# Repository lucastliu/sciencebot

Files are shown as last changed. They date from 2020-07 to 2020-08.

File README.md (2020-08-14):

<!-- PROJECT SHIELDS -->
<!--
*** https://www.markdownguide.org/basic-syntax/#reference-style-links
-->

[][license-url]

<!-- PROJECT LOGO -->
<br />
<p align="center">
  <a href="https://github.com/lucastliu/sciencebot">
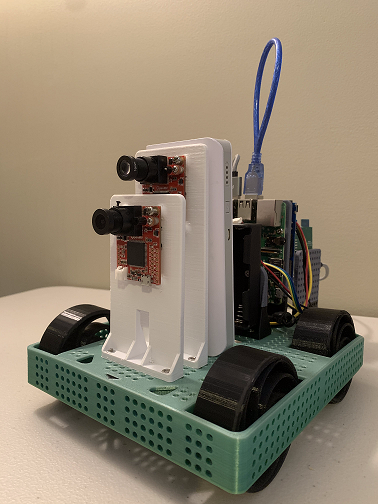
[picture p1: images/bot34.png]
sciencebot
    
  </a>

  <h3 align="center">sciencebot</h3>

  <p align="center">
    A modular & economical research vehicle platform
    <br />
    <a href="https://github.com/lucastliu/sciencebot/wiki">Wiki</a>
    ·
    <a href="https://github.com/lucastliu/sciencebot/blob/master/HARDWARE.md">Hardware</a>
    ·
    <a href="https://github.com/lucastliu/sciencebot/issues">Request Feature</a>
    <br />
    <a href="https://github.com/lucastliu/sciencebot/wiki/System-Capabilities"><b>See sciencebot in action » </b></a>
  </p>
</p>

# Software

Software documentation for setting up the sciencebot, ROS2, and turtlesim.
<!-- TABLE OF CONTENTS -->
## Table of Contents

- [Technologies](#technologies)
- [Project Structure](#project-structure)
- [Getting Started](#getting-started)
  * [Prerequisites](#prerequisites)
    + [Raspberry Pi](#raspberry-pi)
    + [BNO055 IMU](#bno055-imu)
    + [DWM1001](#dwm1001)
    + [OpenMV Cam H7 (Optional)](#openmv-cam-h7--optional-)
    + [Arduino](#arduino)
    + [ROS2 Eloquent Elusor](#ros2-eloquent-elusor)
  * [Installation](#installation)
- [Usage](#usage)
  * [Spin up](#spin-up)
  * [turtlesim basic](#turtlesim-basic)
  * [turtlesim PID control](#turtlesim-pid-control)
  * [sciencebot](#sciencebot)
    + [Manual Drive](#manual-drive)
    + [Automatic XY Waypoint Seeking](#automatic-xy-waypoint-seeking)
    + [Heading Seeking](#heading-seeking)
  * [PlotJuggler](#plotjuggler)
- [Tuning & Modifying](#tuning---modifying)
  * [Tune & MoveTo](#tune---moveto)
  * [ROS Nodes](#ros-nodes)
- [Helpful Tips](#helpful-tips)
- [Resources](#resources)
- [Future](#future)
- [Contributing](#contributing)
- [License](#license)
- [Contact](#contact)

## Technologies

* Raspbian Buster OS
* Arduino
* Python
* C++
* ROS2 Eloquent Elusor

## Project Structure
The `dev_ws` folder contains a full ROS2 based implementation of the vehicle control project.

within `dev_ws`, source code is organized into packages under the `src` folder

Other folders contain basic standalone scripts for individual components (not tied to ROS2 in any way).

See seperate [Hardware Documentation](https://github.com/lucastliu/sciencebot/blob/master/HARDWARE.md) for details on the physical vehicle build, and sensor information

<!-- GETTING STARTED -->
## Getting Started

### Prerequisites

#### Raspberry Pi

  This project was developed on a Raspberry Pi 3B+ running Raspian Buster. Setups that use other Pi hardware or OS versions, or even other Linux devices, will likely operate in a highly similar fashion, but not in the exact same manner.

0. Python 3

    This project requires Python 3. This should be available by default on the Pi with Raspbian Buster.

1. Storage

    Running with Raspbian Buster, the minimum SD card size is 8 GB. However, running this project will require more resources, and a 16 GB card was found to be inadequate as well. A `64 GB micro SD` was used in the build, and is easily sufficient.

2. Virtual Memory

    Due to the limited abilites of an RPi, during installation, it is often useful / necessary to leverage [swap space](https://access.redhat.com/documentation/en-us/red_hat_enterprise_linux/5/html/deployment_guide/ch-swapspace) . This can be achieved by editing the file `/etc/dphys-swapfile`, increasing the `CONF_SWAPSIZE` variable (`1024` seems to be sufficient). Full discussion for RPi 3 B+ can be found [here](https://www.raspberrypi.org/forums/viewtopic.php?t=211804)

3. Remote Access

    This step is optional, but highly recommended. The Pi supports HDMI output, but a wired connection is quite cumbersome, especially for a moving vehicle. There are several options for remote access, one of which is as follows.

    Virtual Network Computing (VNC) will allow one to view and control the Pi from another device wirelessly. Raspbian comes with a native / pre-installed VNC. Full instructions here: [VNC](https://www.raspberrypi.org/documentation/remote-access/vnc/)

    You will want to [setup a static IP Address](https://pimylifeup.com/raspberry-pi-static-ip-address/) as well.

    If the resulting resolution on your host device does not look right, you may need to [adjust the resolution](https://help.realvnc.com/hc/en-us/articles/360002249917-VNC-Connect-and-Raspberry-Pi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).

#### BNO055 IMU

  Communicating with the IMU is done through the [Adafruit_CircuitPython_BNO055 Library](https://github.com/adafruit/Adafruit_CircuitPython_BNO055)

  The Raspberry Pi is also not compatible with the IMU by default due to clock stretching issues. This can be remedied by [switching the Pi to a software implementation of i2c](https://gps-pie.com/pi_i2c_config.htm). This may have negative effects on other sensors that use i2c.

#### DWM1001

  Programming our DWM1001 positioning sensors requires pyserial, which can be acquired by opening a terminal and running

  ```sh
  pip install pyserial
  ```
  
  Programming DWM1001 Modules can be done through [TeraTerm](https://osdn.net/projects/ttssh2/releases/).

  Follow the [Quick Deployment Guide](https://www.decawave.com/wp-content/uploads/2019/03/DWM1001_Gateway_Quick_Deployment_Guide.pdf) for software installation requirements. Refer to this repository's HARDWARE guide for full details. If you have an Android device, see the guide for remote programming using Android.

#### OpenMV Cam H7 (Optional)

  WIP. Not currently integrated in ROS movement, but has standalone functionality. Relevant files under `camera` folder.

  [OpenMV IDE](https://openmv.io/pages/download)

  [OpenMV Documentation](https://docs.openmv.io/)

  Upload `camera_constants.py` and `main.py` (Files available in camera/h7 folder) to device using micro USB cable. `main.py` is the script that will automatically run upon powering on the H7 cam. See `cam_example.py` for how to recieve data from the H7 Cam onto the Raspberry Pi (host device).

#### Arduino

  The Arduino is our motor microcontroller, solely in charge of sending PWM signals to our motors. 

  [Download Arduino IDE](https://www.arduino.cc/en/main/software)

  Our microcontroller code also requires downloading the [AFMOTOR support library](https://learn.adafruit.com/adafruit-motor-shield/library-install)

#### ROS2 Eloquent Elusor

Your primary and best reference is the [ROS2 website](https://index.ros.org/doc/ros2/)

Their [tutorials](https://index.ros.org/doc/ros2/Tutorials/#tutorials) are also very informative, and a great place to start at. Several of the beginner example packages have been provided.

This project was built for ROS2 Eloquent: [Instructions for installing from source](https://index.ros.org/doc/ros2/Installation/Eloquent/Linux-Development-Setup/)

The build process may require several attempts, as ROS does not have Tier 1 support for the Pi. In order to reduce the strain on the Pi, add the following flag modifications to build commands:

```sh
MAKEFLAGS="-j1 -l1" colcon build  --executor sequential
```
Installing ROS2 may take a considerable amount of time.

### Installation
 
1. On the Pi, open a terminal and clone sciencebot
```sh
git clone https://github.com/lucastliu/sciencebot.git
```
2. Using the Arduino IDE, Upload [SerialMotor.ino](https://github.com/lucastliu/sciencebot/blob/master/motors/SerialMotor/SerialMotor.ino) to the Arduino

3. [Create an ROS workspace](https://index.ros.org/doc/ros2/Tutorials/Workspace/Creating-A-Workspace/) under dev_ws. Pay special attention to sourcing the overlay and underlay.

4. Build the project
```sh
cd .../dev_ws/src
```
```sh
colcon build --symlink-install
```

This should build all sciencebot ROS2 packages.
<!-- USAGE EXAMPLES -->
## Usage

### Spin up

Open a terminal and navigate to the project
```sh
cd .../dev_ws
```

Source the overlay

```sh
. install/setup.bash
```

### turtlesim basic

Run this first to confirm that the software has installed correctly.
Turtlesim is also a useful simulation for developing basic control theory in a controlled, simplified environment.

Follow the Spin up steps.

```sh
ros2 run turtlesim turtlesim_node
```
You should see a GUI pop-up with a turtle if project installation was successful. Close the simulation and window.

### turtlesim PID control

Control the turtle using PID goal seeking.

Complete the Spin up steps.

Run the launch file
```sh
ros2 launch nav turtlesim.launch.py
```

Wait for indication that "Turtle PID Node is Live"

In a seperate terminal, follow the Spin up steps and run

```sh
python3 ./src/nav/nav/clients/tune_position_pid_client.py
```

You will be prompted for a goal position X Y, as well as PID parameters.

Here are some good defaults:

```sh
Desired X Y: 6 7
Enter linear PID Constants : 1.5 0 0
Enter Angular PID Constants : 6 0 0
```

If you have chosen good parameters, the turtle will move to the desired setpoint.

### sciencebot

Running of the sciencebot requires the relevant hardware components to be installed, as described in [HARDWARE](https://github.com/lucastliu/sciencebot/blob/master/HARDWARE.md)

#### Manual Drive

Follow these steps to manually drive the vehicle with a keyboard.

Complete Spin Up steps.

Run the motor node

```sh
ros2 run nav motors
```

Open a second terminal, and complete Spin up steps.

Run the teleop node

```sh
ros2 run teleop_twist_keyboard teleop_twist_keyboard
```

Begin driving. See [teleop twist keyboard](https://github.com/lucastliu/sciencebot/tree/master/dev_ws/src/teleop_twist_keyboard) for additional drive details.

#### Automatic XY Waypoint Seeking
Complete Spin up steps.

Run the launch file

```sh
ros2 launch nav pose.launch.py
```
If sensors are correctly hooked up, the terminal should begin displaying position and heading.

Open a new terminal, and complete the spin up steps.

Run the vehicle controller node of your choice, i.e.
```sh
ros2 run nav mixed
```

Open a new terminal, complete the spin up steps.

Run the request client script

```sh
python3 ./src/nav/nav/clients/run_position_pid_client.py
```
input your desired destination
```sh
Desired X Y: 1.5 1.5
```

The vehicle should begin moving to the waypoint in accordance with controller node policy.

#### Heading Seeking
Complete Spin up steps.

Run the launch file

```sh
ros2 launch nav pose.launch.py
```
If sensors are correctly hooked up, the terminal should begin displaying heading updates.

Open a new terminal, and complete the spin up steps.

Run the vehicle heading controller node of your choice, i.e.
```sh
ros2 run nav imupid
```

Open a new terminal, complete the spin up steps.

Run the request client script

```sh
 python3 ./src/nav/nav/clients/heading_pid_client.py 
```
input your desired heading angle, and parameters

```sh
Desired Angle (Degrees): 200
Enter Angular PID Constants : .5 .25 .0008
```

The vehicle should begin turning to the setpoint in accordance with controller node policy.

### PlotJuggler

PlotJuggler is an ROS package useful for collecting and visualizing data. It is capable of streaming [ROS2 topics](https://index.ros.org/doc/ros2/Tutorials/Topics/Understanding-ROS2-Topics/) in real time, which can be very helpful for observing and debugging the vehicle system, or any ROS2 system.

sciencebot provides a custom modified version of PlotJuggler designed to work on the Raspberry Pi 3B+ with ROS2 Eloquent.

PlotJuggler is installed like any other ROS2 Package. Plotjuggler also requires that plotjuggler_msgs has also been built.

Complete spin up steps.

Build the packages

```sh
cd .../dev_ws
```

```sh
colcon build --packages-select plotjuggler_msgs
```

```sh
colcon build --packages-select plotjuggler
```

After installation, Complete the Spin Up steps.

Then run

```sh
ros2 run plotjuggler PlotJuggler
```

The PlotJuggler GUI should pop-up.

pg

Livestreaming ROS topic data can be achieved as follows:

0. Start your ROS nodes (and ensure topics are being published to)
1. Navigate in the top menu to **Streaming > Start ROS2 Topic Subscriber**
2. Select desired topics and click **OK**
3. Drag desired topics from sidebar onto plot.
4. Information should begin streaming, as indicated at the bottom right **Streaming ON**
5. Use the toolbar at the top right to adjust plot details, and add subplots

See [PlotJuggler source repository](https://github.com/facontidavide/PlotJuggler) for further usage instructions and more information. 

## Tuning & Modifying

### Tune & MoveTo

There are several prebuilt [ROS Actions](http://design.ros2.org/articles/actions.html)
available within sciencebot, some for tuning parameters, some for running a prebuilt system.
These actions are defined within the `custom_interfaces` package, under `dev_ws/src/custom_interfaces`.

The `Tune` Action is defined as follows:

```
float64 x_dest
float64 y_dest
float64[3] linear
float64[3] angular
---
float64 x_final
float64 y_final
---
float64 x_curr
float64 y_curr
```

This means that an action client must supply the first set of parameters: an X, Y destination, and 2 sets of PID parameters for an angular and linear [PID Controller](https://github.com/lucastliu/sciencebot/wiki/PID-Controller). The Action server is required to provide XY position updates, as well as a final XY position after execution. Thus, the Tune action is useful for determining parameters, as new weights can be given on each run.

On the other hand, the `MoveTo` Action is defined as follows:

```
float64 x_dest
float64 y_dest
---
float64 x_final
float64 y_final
---
float64 x_curr
float64 y_curr
```

While similar to `Tune`, it does not accept parameter weights. Using the `MoveTo` can be thought of as the production version of the action, where the weights have already been determined, and only goal seeking is perfomed.

The `Heading` action is similar to `Tune`, except it is for seeking a goal heading rather than an XY. It is defined as follows:

```
float64 dest_angle
float64[3] angular
---
float64 final
---
float64 curr
```

Use these actions, or create new ones, to either fine tune or run your sciencebot for various tasks.

### ROS Nodes
Adding a new node to the `nav` package is an easy way to extend the sciencebot ROS ecosystem. It is helpful to use existing nodes as a template.

Navigate to the nav package, and move into the subfolder also named `nav`

```sh
cd .../dev_ws/src/nav/nav
```
lu
Create your new python file, following ROS2 Node conventions.

Return to the root of the `nav` package,

```sh
cd .../dev_ws/src/nav/
```
Modify `setup.py`, adding your new node into the list of `console_scripts`, following the convention `'NODE_NAME = nav.SUBPATH_TO_FILE:main'`

Navigate to root of ROS workspace

```sh
cd .../dev_ws
```

rebuild the nav package

```sh
colcon build --packages-select nav
```

Now, after completing Spin up steps, you should be able to launch your new node in a terminal using

```sh
ros2 run nav NODE_NAME
```

## Helpful Tips

To build just a single ROS package, use the `--packages-select` flag

Example:

```sh
colcon build --packages-select nav
```

ROS nodes can have their python components linked, so that changes in the script are automatically reflected in the next launch of the node (no rebuild needed). Use the `--symlink-install` flag when building. 

Example:

```sh
colcon build --symlink-install nav
```

## Resources
[ROS2](https://index.ros.org/doc/ros2/)

[ROS answers](https://answers.ros.org/questions/)

[r/ROS](https://www.reddit.com/r/ROS/)

[Raspberry Pi Forums](https://www.raspberrypi.org/forums/)

## Future

* H7 Camera Computer Vision Integration

* 3D printed components redesign

* Advanced Sensor Fusion

* Drivetrain change

<!-- CONTRIBUTING -->
## Contributing

Contributions are key to any open source project, and are definitely welcome here!

1. Fork the Project, and clone it (`git clone git@github.com:YOUR_USERNAME/sciencebot.git`)
2. Create your Feature Branch (`git checkout -b FEATURE_NAME`)
3. Commit your Changes (`git commit -m 'INFORMATIVE IMPROVEMENT MESSAGE'`)
4. Push to the Branch (`git push origin FEATURE_NAME`)
5. Open a Pull Request

<!-- LICENSE -->
## License

    Copyright © 2020 Lucas Liu

    sciencebot

    sciencebot is free software: you can redistribute it and/or modify
    it under the terms of the GNU General Public License as published by
    the Free Software Foundation, either version 3 of the License, or
    (at your option) any later version.

    sciencebot is distributed in the hope that it will be useful,
    but WITHOUT ANY WARRANTY; without even the implied warranty of
    MERCHANTABILITY or FITNESS FOR A PARTICULAR PURPOSE.  See the
    GNU General Public License for more details.

    You should have received a copy of the GNU General Public License
    along with sciencebot.  If not, see <https://www.gnu.org/licenses/>.

This repository includes modified versions of other source code from the ROS open source community. The relevant subfolders each have their own license. All other files fall under the GPLv3 license as described above.

<!-- CONTACT -->
## Contact

Lucas Liu  - lucas.liu AT duke.edu

<!-- MARKDOWN LINKS & IMAGES -->
<!-- https://www.markdownguide.org/basic-syntax/#reference-style-links -->
[license-shield]: https://img.shields.io/badge/License-GPLv3-blue.svg
[license-url]: https://github.com/lucastliu/sciencebot/LICENSE.txt
[product-screenshot]: images/screenshot.png

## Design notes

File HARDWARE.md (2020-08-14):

<!-- PROJECT SHIELDS -->
<!--
*** https://www.markdownguide.org/basic-syntax/#reference-style-links
-->

[][license-url]

<!-- PROJECT LOGO -->
<br />
<p align="center">
  <a href="https://github.com/lucastliu/sciencebot">
    sciencebot
  </a>

  <h3 align="center">sciencebot</h3>

  <p align="center">
    A modular & economical research vehicle platform
    <br />
    <a href="https://github.com/lucastliu/sciencebot/wiki">Wiki</a>
    ·
    <a href="https://github.com/lucastliu/sciencebot/blob/master/README.md">Software</a>
    ·
    <a href="https://github.com/lucastliu/sciencebot/issues">Request Feature</a>
    <br />
    <a href="https://github.com/lucastliu/sciencebot/wiki/System-Capabilities"><b>See sciencebot in action » </b></a>

  </p>
</p>

# Hardware

Guide for physical vehicle construction, as well as sensor information.

<!-- TABLE OF CONTENTS -->
## Table of Contents
- [Hardware Technologies](#hardware-technologies)
- [Overview Shots](#overview-shots)
- [Getting Started](#getting-started)
  * [Prerequisites](#prerequisites)
  * [Installation](#installation)
    + [Base Chassis, Mounts & Wheels](#base-chassis--mounts---wheels)
    + [Wheels](#wheels)
    + [Raspberry Pi](#raspberry-pi)
    + [Arduino Motor Microcontroller](#arduino-motor-microcontroller)
    + [BNO055 IMU](#bno055-imu)
    + [DWM1001](#dwm1001)
    + [OpenMV Cam H7](#openmv-cam-h7)
- [Testing & Troubleshooting](#testing---troubleshooting)
- [License](#license)
- [Contact](#contact)

## Hardware Technologies
* [Raspberry Pi 3B+](https://www.raspberrypi.org/products/raspberry-pi-3-model-b-plus/)
* [Arudino Uno](https://store.arduino.cc/usa/arduino-uno-rev3)
* [Arduino Motor Shield](https://store.arduino.cc/usa/arduino-motor-shield-rev3)
* [Adafruit BNO055 Absolute Orientation Sensor](https://learn.adafruit.com/adafruit-bno055-absolute-orientation-sensor)
* [DWM1001C Module](https://www.decawave.com/product/dwm1001-module/) x4
* [DC Gearbox Motor - "TT Motor"](https://www.adafruit.com/product/3777) x4
* [Open MV Cam H7](https://openmv.io/products/openmv-cam-h7) x2
* [12V DC - 5V DC Voltage Step Down Regulator](https://www.amazon.com/Car-Voltage-Converter-Regulator-Smartphone/dp/B07RYT4KKK)
* [18650 Batteries](https://www.batteryjunction.com/18650.html) x3
* [18650 Battery Housing](https://www.amazon.com/Aokin-Battery-Storage-Parallel-Batteries/dp/B07Q13T3RH)
* [Portable USB Charger](https://www.amazon.com/dp/B00X5SP0HC/) x4
* [USB Cable Type A/B](https://store.arduino.cc/usa/usb-2-0-cable-type-a-b)
* [USB to USB Micro Cable](https://www.amazon.com/AmazonBasics-Male-Micro-Cable-Black/dp/B0711PVX6Z) x8
* 3D Printed Chassis, Wheels, Components
* Assorted wires, M3 screws / nuts, zipties, command strips, etc

## Overview Shots
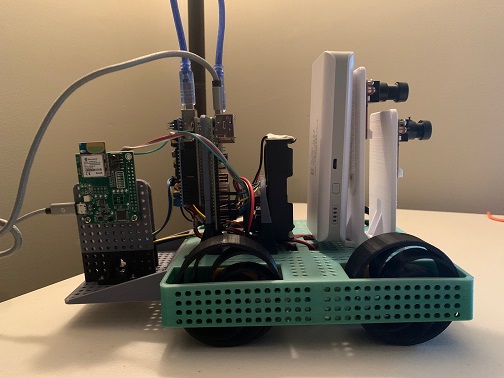
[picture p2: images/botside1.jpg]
botside

botside2
botbottom
bottop

<!-- GETTING STARTED -->
## Getting Started

### Prerequisites

Gather parts. Acquire appropriate screwdriver. Multimeter also useful for debugging.

### Installation

#### Base Chassis, Mounts & Wheels

The basic frame, as well as modular mount pieces and the wheels of the sciencebot are 3D printed. Many components have 3mm holes arranged in grid fashion, which are great for making components adaptable and modular. Connections can be made with M3 screws, zipties, or with other parts. A variety of parts are provided under the [3D_parts folder](https://github.com/lucastliu/sciencebot/tree/master/3D_parts), but also feel free to make your own!

In addition, here are some links to OnShape files for the 3D parts:

[Base](https://cad.onshape.com/documents/a6b3f805fb03e809b82d1add/w/56e20282fa9ed432ed0b3781/e/dcdab560d54729ee209a3d05)

[Additional Mounts](https://cad.onshape.com/documents/7904cea1c97a22124acc52eb/w/d508e8c8701c0da82f3e15ee/e/760d4528fb9caa9cfacff0b7)

[Additional Generics](https://cad.onshape.com/documents/96bc3dd7c7456dd4e1d48dcb/w/7a2bb739f9d9a8153bb0c78c/e/8193ef8f2d9a02fdaa290d24)

#### Wheels

Attach wheel to motor shaft. Place thread ziptie through motor and chassis base. Hand dexterity required here. "Pre-bending" the ziptie before threading can make this easier. 
botbottomfit
botbottom1
Thread power and ground wires from motor through chassis. Repeat for all wheels.
botbottom2

#### Raspberry Pi

The Raspberry Pi is the central brain of the vehicle. All other components will be hooked up to the Pi.

pi_pins


The preferred method of powering the Pi is to simply connect a micro-usb cable to a USB power bank. This will allow for a significantly longer operating time, as the Pi consumes much more power than the Arduino. While developing / installing, one can also use wall power.

Alternatively, one can power the Pi through the 18650s by wiring the 12V battery source to the 12V input of the voltage converter, then connecting the 5V output of the converter to the micro-usb power port on the Pi. With this setup, the battery will drain quickly, as it must power both the Pi and Arduino.

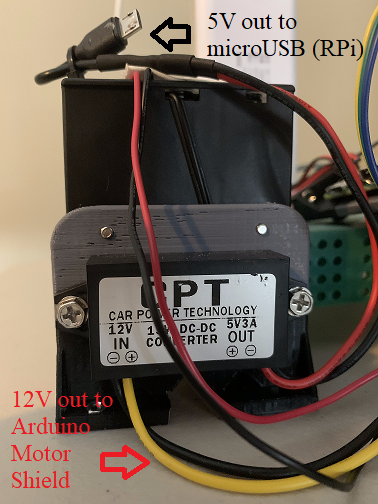
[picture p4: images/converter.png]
converter


#### Arduino Motor Microcontroller

Our Arduino Uno will serve as the motor microcontroller. Attatch the motor shield to the Arduino, and wire the motors to the shield. using the USB A/B Cable, connect the Arduino to the Raspberry Pi.

ardfront

The Pi and Arduino are vertically mounted on the base

ardside

Test the motors by running `motor_test.py` (located under motors folder) on the Pi. Note the direction of spin for each wheel. Adjust the code in the Arduino `SerialMotor.ino` file, or the `SerialMotor.py` file to correct. Note that these files exist in the standalone motors folder, but also under dev_ws/src/nav/nav/motors for the ROS2 implementation. Changes need to be made in the dev_ws subdirectory to take effect for the ROS implementation. Same goes for the standalone.

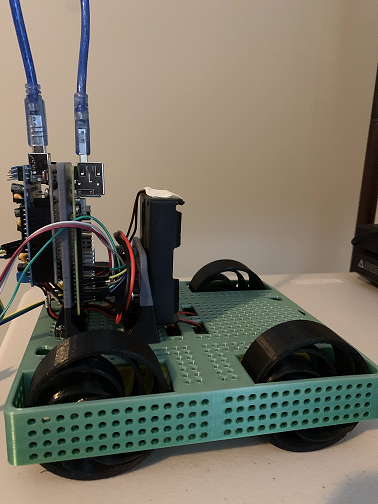
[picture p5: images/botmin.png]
botmin


#### BNO055 IMU

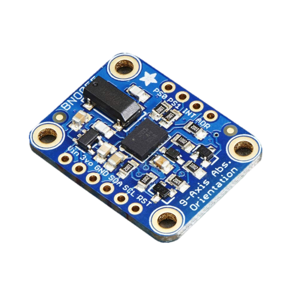
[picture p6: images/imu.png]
imu


1. Connect the Power, Ground, SCL, and SDA pins to the correct pinouts on the Pi. [Sensor Pinouts](https://learn.adafruit.com/adafruit-bno055-absolute-orientation-sensor/pinouts)

2. Enable I2C on your Pi **(Pi > Preferences > Raspberry Pi Configuration > Interfaces)**

3. Run the [IMU example script](https://github.com/lucastliu/sciencebot/blob/master/imu/example.py) to confirm data is flowing properly to the Pi.

Note: IMU data is much better when properly calibrated, though heading data is still usable even without calibration. Calibration is achieved automatically by moving the vehicle/sensor in [predefined motion sequences](https://www.mathworks.com/help/supportpkg/arduino/ref/bno055imusensor.html) (see the "More About" section). 

Calibration status can be accessed in the same way as other sensor fields in the example script. The two relevant metrics are `sensor.calibration_status` (3 being the best) and `self.sensor.calibrated` (A boolean value for whether all calibration is complete).

User beware: The IMU will initially set whichever heading it is pointed to as "heading zero," but will automatically adjust itself to true due east as zero as it calibrates. Clockwise rotation corresponds to larger angles, which are given in degrees. Wrap-around to zero at 360 degrees (though occasionally the IMU will give readings up to 370). Make sure to convert to your appropriate co-ordinate system.

#### DWM1001

dwm

Follow the [Quick Deployment Guide](https://www.decawave.com/wp-content/uploads/2019/03/DWM1001_Gateway_Quick_Deployment_Guide.pdf)

The guide is very extensive, so here are some important highlights:

1. Make sure each DWM has up to date firmware, as described on page 9 of the guide.

2. Our main interest is to USB hookup each DWM to a computer, and use TeraTerm to program each DWM in UART mode. Instructions for this start on page 11 of the Quick Deployment Guide. You will need at minimum a DWM configured for tag mode (the one on the vehicle), an initator DWM, and at least 2 anchor DWMs. You must program the x,y,z (arbitrary origin) of the initiator and anchors, then place the modules in your physical space accordingly. Orient all DWMs as shown in the picture, with the blue-colored "protrusion" at the top of the module.

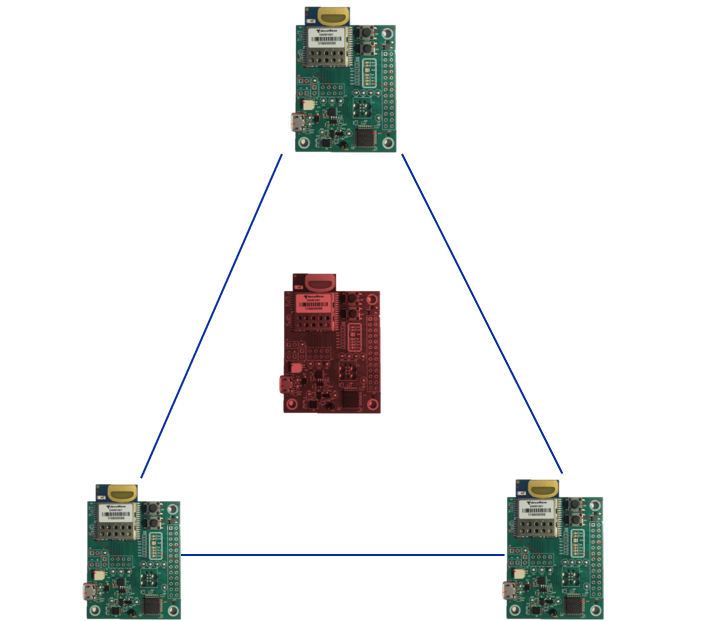
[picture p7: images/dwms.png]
dwms


It tends to be easiest to set one DWM position at the origin, and place the other tags relative to the origin DWM.

3. After initial setup, we communicate from the Pi using [this API]( https://www.decawave.com/sites/default/files/dwm1001-api-guide.pdf). In particular, we use the `lec` mode (see API page 63) to get positioning data.

#### OpenMV Cam H7

camh7

Cameras are attached to 3D printed mounts. Wire micro-usb cable to Pi's USB ports (USB provides channel for Data and power).

cam

Camera lens can be swapped out for different FOV and other properties. Standard M2 Lens mount.

## Testing & Troubleshooting

The various components port addresses need to be correctly determined and set during initialization. On the Pi, open a terminal and run
```sh
dmesg | grep -i usb
```
to see devices and respective ports. For instance, the Arduino may come up under port name `/dev/ttyACM1`. When the SerialMotor object is constructed, make sure to give it the correct port. This applies for any device connected to the Pi through USB.

During ROS operation, poorly formed code / nodes may cause ungraceful shutdown, and cause the vehicle to behave undesirably. Power cycling both the Pi and the Arduino will give you a fresh start. 

If the motors seem to continually spin (likely from the last motor command before communication failure), after power cycling, modify the `motor_test.py` script to set both motors to zero, and run the script to stop the motors.

<!-- LICENSE -->
## License

    Copyright © 2020 Lucas Liu

    sciencebot

    sciencebot is free software: you can redistribute it and/or modify
    it under the terms of the GNU General Public License as published by
    the Free Software Foundation, either version 3 of the License, or
    (at your option) any later version.

    sciencebot is distributed in the hope that it will be useful,
    but WITHOUT ANY WARRANTY; without even the implied warranty of
    MERCHANTABILITY or FITNESS FOR A PARTICULAR PURPOSE.  See the
    GNU General Public License for more details.

    You should have received a copy of the GNU General Public License
    along with sciencebot.  If not, see <https://www.gnu.org/licenses/>.

This repository includes modified versions of other source code from the ROS open source community. The relevant subfolders each have their own license. All other files fall under the GPLv3 license as described above.

<!-- CONTACT -->
## Contact

Lucas Liu  - lucas.liu AT duke.edu

<!-- MARKDOWN LINKS & IMAGES -->
<!-- https://www.markdownguide.org/basic-syntax/#reference-style-links -->
[bot34]: images/bot34.png
[bot_front]: images/botfront.png
[bot_side_1]: images/botside1.jpg
[bot_side_2]: images/botside2.jpg
[bot_bottom]: images/bottom.png
[bot_bottom_1]: images/bottom_1.png
[bot_bottom_2]: images/bottom_2.png
[bot_fitting]: images/bottom_fitting.png
[bottop]: images/bottop.png
[botmin]: images/botmin.png
[pi_pins]: images/Pi-GPIO-Pinout-Diagram.png
[dwm]: images/dwm.png
[dwms]: images/dwms.png
[camh7]: images/camh7.png
[imu]: images/imu.png
[converter]: images/converter.png
[case]: images/case.png
[cam]: images/cam.png
[ardfront]: images/ardfront.png
[ardside]: images/ardside.png
[license-shield]: https://img.shields.io/badge/License-GPLv3-blue.svg
[license-url]: https://github.com/lucastliu/sciencebot/LICENSE.txt
[product-screenshot]: images/screenshot.png

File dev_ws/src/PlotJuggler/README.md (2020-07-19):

PlotJuggler

| ROS (Kinetic / Melodic)  | ROS2 (Eloquent) | Windows (Mingw)  |
|---|---|---|
|  |  |  |




# PlotJuggler 2.8.3

QT5 based application to display time series in plots, using an intuitive "drag and drop" interface.

It can be used either to:

- load __static data from file__ or 
- connect to live __streaming__ of data.

Its functionality can be easily extended through __plugins__.

To understand what PlotJuggler can do for you, take a look to the following video [PlotJuggler on Vimeo](https://vimeo.com/214389001) 

PlotJuggler

## Supported formats

- CSV
- Rosbags / ROS topics (both ROS1 and ROS2)
- ULog (PX4)
- Your custom format... [contact me to know more](https://www.plotjuggler.io/support).

## Compute calculations and transform your data

It is now possible to create custom timeseries! Simply write your own
**JavaScript** or **Lua** function and apply it to one of more existing timeseries.

Many thanks to [@1r0b1n0](https://github.com/1r0b1n0), who developed the
initial version of this feature, and to our first __sponsor__, 
a robotics company that made a donation, but prefers to remain anonymous for the time being.

Watch this video to learn how to use it.

Custom timeseries (https://vimeo.com/311245098)

## "Download and Run" (Ubuntu 16.04 Xenial or later)

For those of you that can't wait and want to get their hands dirty, just download the AppImage:

ROS1 only: [PlotJuggler-2.7.x-x86_64.AppImage](https://github.com/facontidavide/PlotJuggler/releases/download/2.7.0/PlotJuggler-2.7.0-x86_64.AppImage).
   
Do not forget to make it executable with the command 

    chmod +x ./PlotJuggler-*-x86_64.AppImage

## How to build (without ROS plugins)

Clone the repository as usual:

      git clone https://github.com/facontidavide/PlotJuggler.git

The only binary dependency that you need installed in your system is Qt5. 
On Ubuntu the debians can be installed with the command:

    sudo apt-get -y install qtbase5-dev libqt5svg5-dev qtdeclarative5-dev qtmultimedia5-dev libqt5multimedia5-plugins
    
On Fedora:

    sudo dnf install qt5-qtbase-devel qt5-qtsvg-devel qt5-qtdeclarative-devel qt5-qtmultimedia-devel
    
Then compile using cmake (qmake is NOT supported):

     mkdir build; cd build
     cmake ..
     make
     sudo make install
 
 Note: the plugins need to be installed in the same folder of the executable or in __/usr/local/lib/PlotJuggler/__.

## How to build (ROS/ROS2 users)

 The easiest way to install PlotJuggler is through the command:
 
    sudo apt-get install ros-${ROS_DISTRO}-plotjuggler 

Nevertheless, if you want to compile it from source, for instance to try the very latest version on the master branch, 
you **must** build PlotJuggler using either **catkin** or **colcon**, otherwise the ROS related plugins will **not** be included.

Compiling with catkin_tools:

    mkdir -p ws_plotjuggler/src; cd ws_plotjuggler/src
    git clone https://github.com/facontidavide/PlotJuggler.git
    cd ..
    rosdep install --from-paths src --ignore-src --rosdistro=${ROS_DISTRO} -y
    catkin build
    source devel/setup.bash
    
You should see the following message at the beginning of the compilation step:

    "PlotJuggler is being built using CATKIN. ROS plugins will be compiled"

Both the executable and the plugins will be created in __ws_plotjuggler/devel/lib/plotjuggler__.

To run the application, use the command:

    rosrun plotjuggler PlotJuggler  

# If you like PlotJuggler...

PlotJuggler required a lot of work to be developed; my goal is to build the most
intuitive and powerfull tool to visualize data and timeseries.

If you find PlotJuggler useful, consider making a donation on 
[PayPal](https://www.paypal.me/facontidavide) or 

If you use PlotJuggler at work, your company can become a __sponsor__ and support 
the development of those specific features they need.

[Contact me](https://www.plotjuggler.io/support) for more details.

# Stargazers over time

Stargazers over time (https://starchart.cc/facontidavide/PlotJuggler)

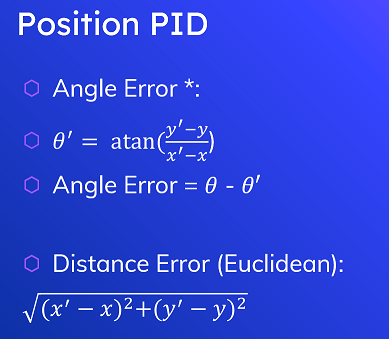
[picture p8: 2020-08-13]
images/pos_pid.png

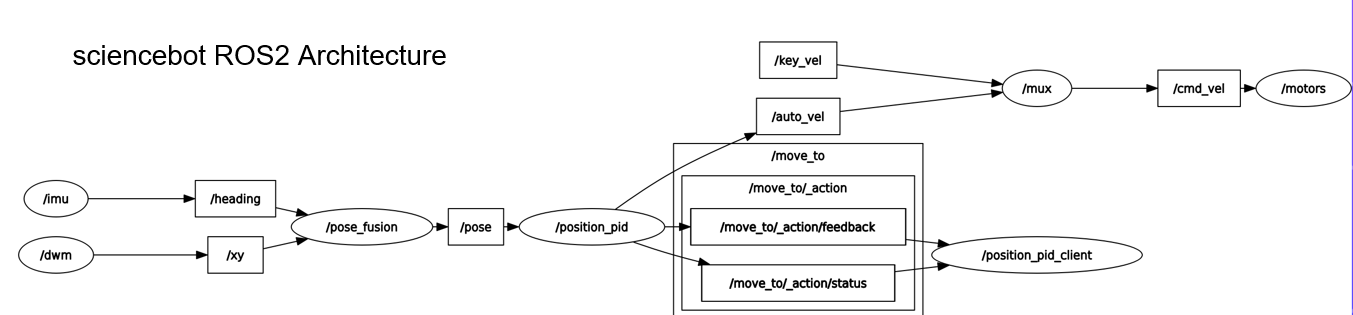
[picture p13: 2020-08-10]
images/arch.png

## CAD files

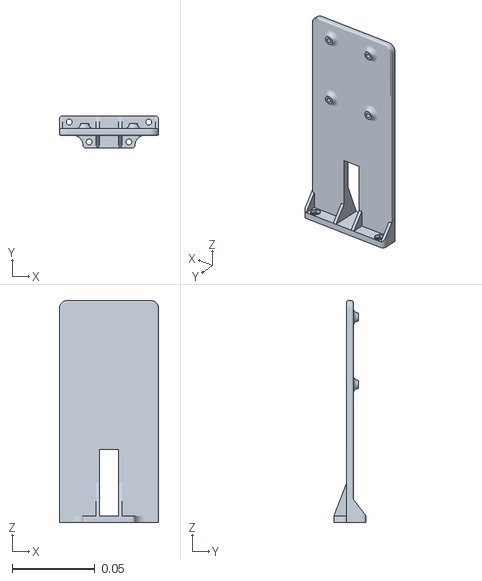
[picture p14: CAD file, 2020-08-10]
3D_parts/single_high_mount.stl
0.06 x 0.0195 x 0.134

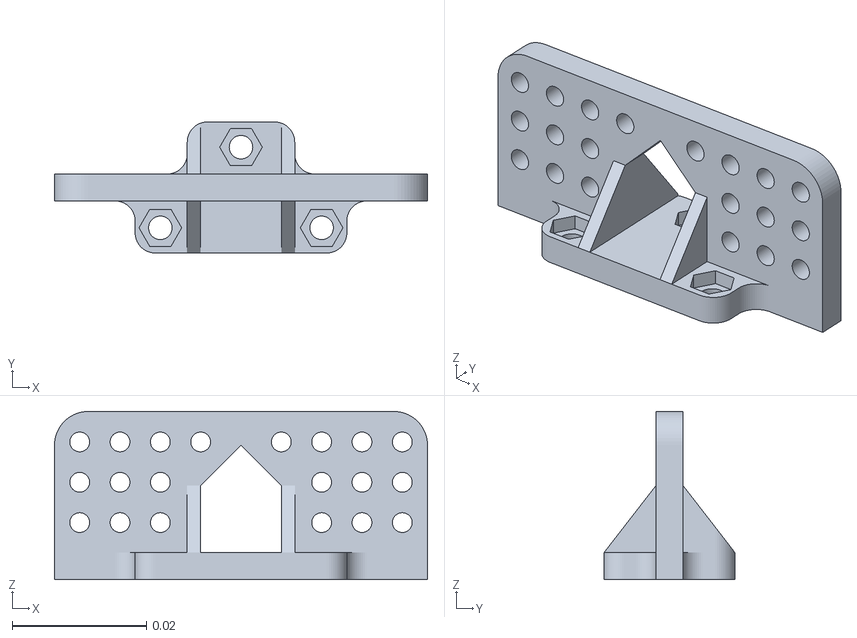
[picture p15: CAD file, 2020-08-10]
3D_parts/tiny_mount.stl
0.0555 x 0.0195 x 0.025

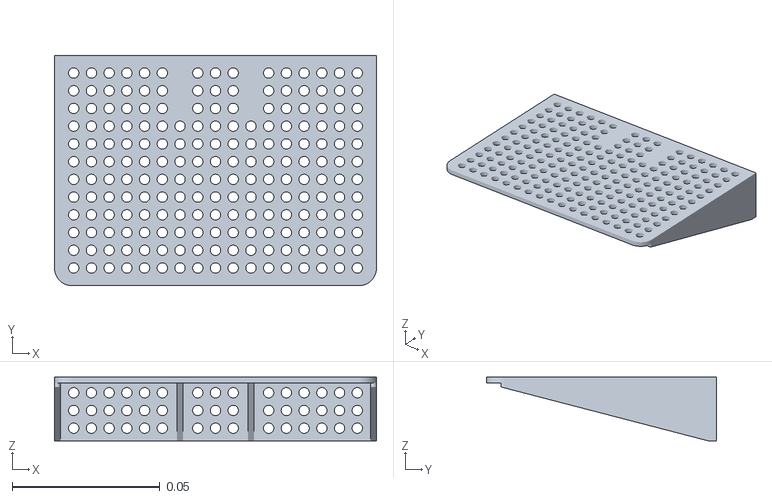
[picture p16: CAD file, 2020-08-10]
3D_parts/deck_extension.stl
0.109 x 0.078 x 0.0215

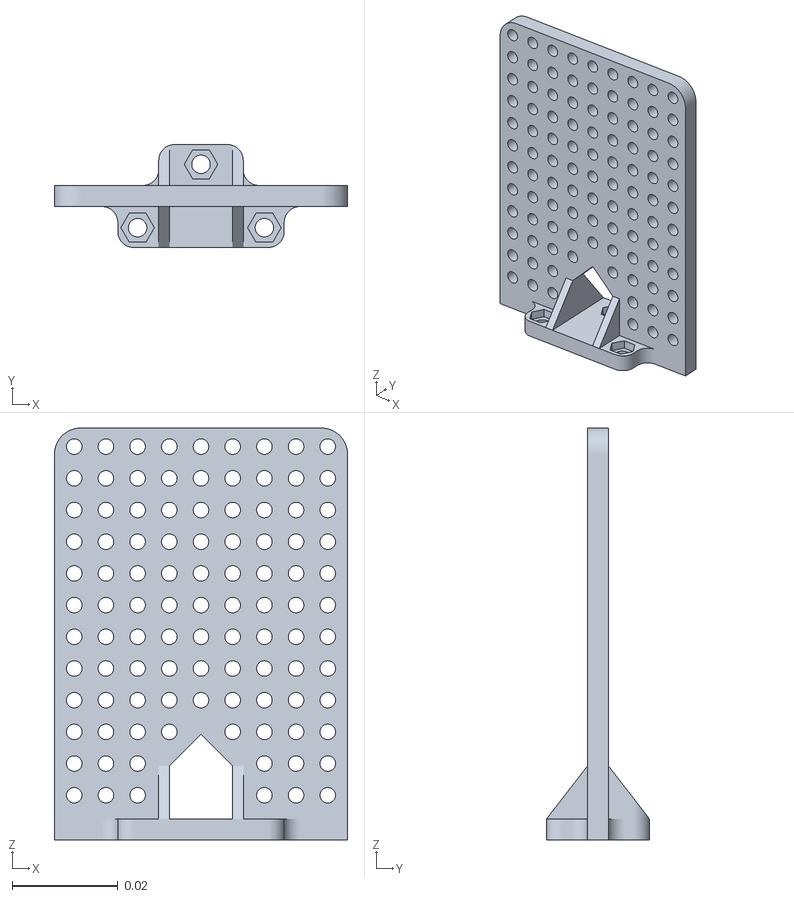
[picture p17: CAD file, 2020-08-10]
3D_parts/generic_mount.stl
0.0555 x 0.0195 x 0.078

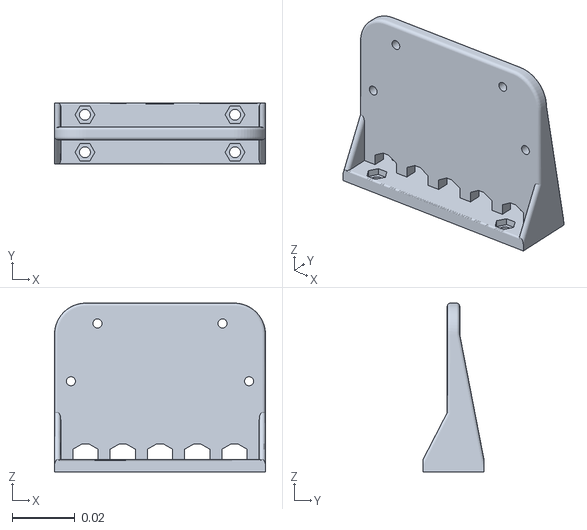
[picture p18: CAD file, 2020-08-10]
3D_parts/batt_regulator_mount.stl
0.0675 x 0.0195 x 0.054

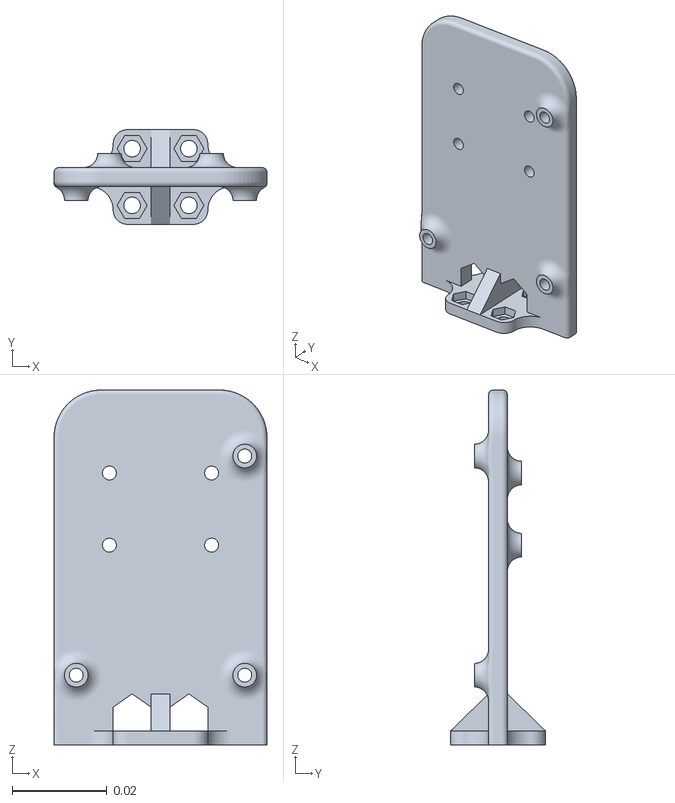
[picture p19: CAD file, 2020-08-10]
3D_parts/DWM_BNO055_mount.stl
0.045 x 0.02 x 0.075

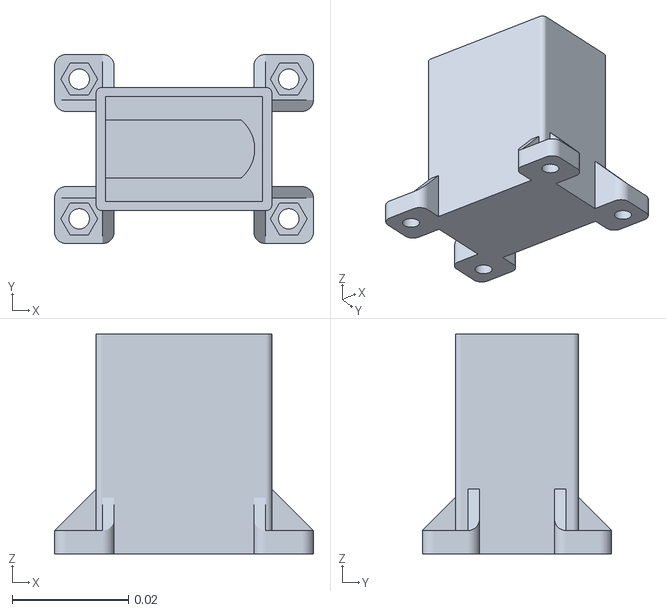
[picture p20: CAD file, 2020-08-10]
3D_parts/9V_clip_mount.stl
0.0445 x 0.0325 x 0.0378

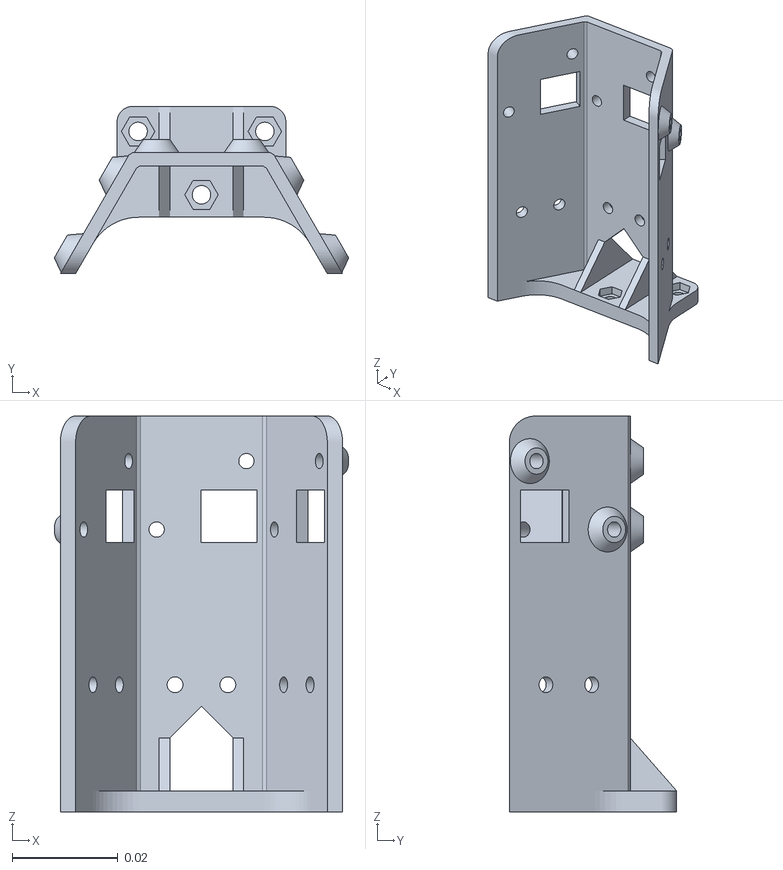
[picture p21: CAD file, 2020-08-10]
3D_parts/sonar_mount.stl
0.0558 x 0.0317 x 0.075

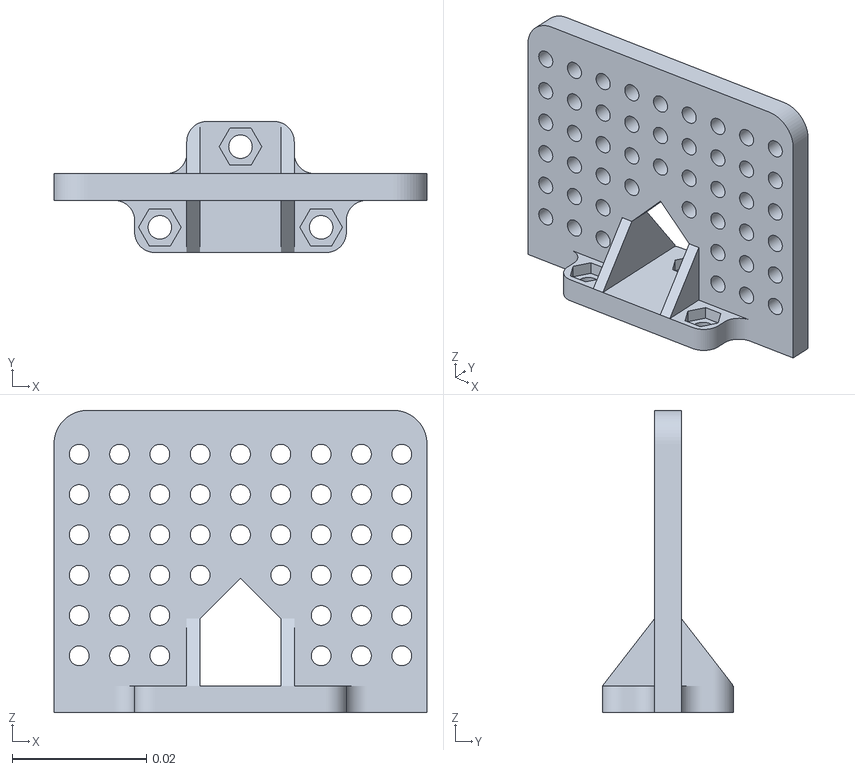
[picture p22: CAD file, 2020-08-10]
3D_parts/short_mount.stl
0.0555 x 0.0195 x 0.045

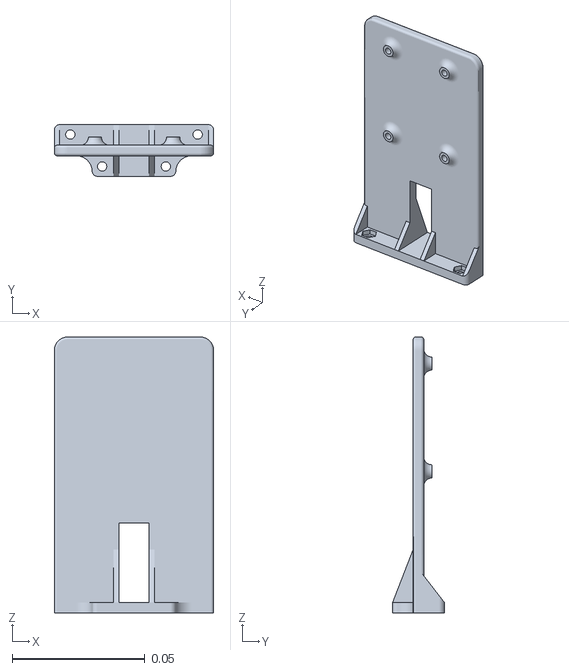
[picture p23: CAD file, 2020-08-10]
3D_parts/cam_low_mount.stl
0.06 x 0.0195 x 0.104

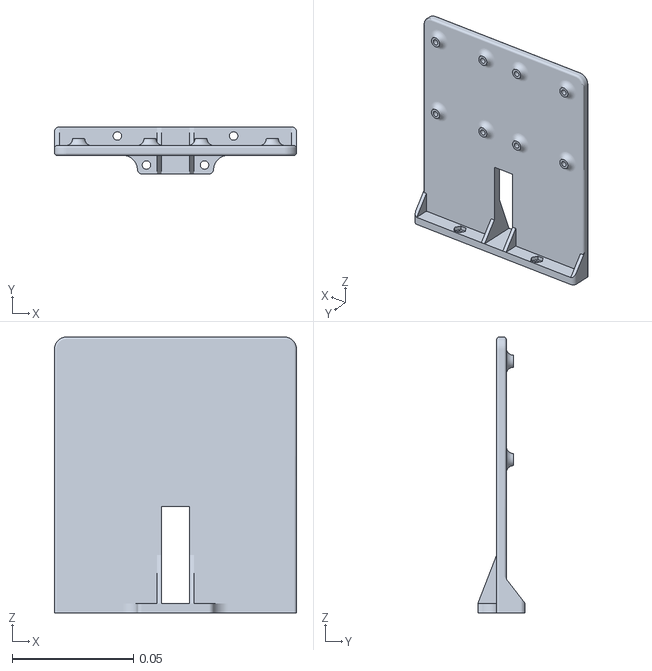
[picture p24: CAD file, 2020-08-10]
3D_parts/dual_cam_mount.stl
0.1 x 0.0195 x 0.114

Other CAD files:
3D_parts/larger_opening_mount.stl
3D_parts/rpi_uno_mount.stl

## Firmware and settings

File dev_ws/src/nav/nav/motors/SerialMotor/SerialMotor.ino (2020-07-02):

/**
 * Packets are of the form "z<port> <power>\n".
 * port: integer 1..4
 * power: float -1..1
 */

#include <AFMotor.h>

AF_DCMotor motor1(1);
AF_DCMotor motor2(2);
AF_DCMotor motor3(3);
AF_DCMotor motor4(4);
AF_DCMotor motors[4] = {motor1, motor2, motor3, motor4};

/**
 * Sets the percentage of power and direction of the specified motor.
 * @param motor the motor whose power should be set
 * @param power -1..1 the power and direction to set the motor to
 */
void setPower(int port, float power) {
  motors[port - 1].run(power >= 0 ? FORWARD : BACKWARD);
  motors[port - 1].setSpeed(abs(power * 255));
}

void setup() {
  Serial.begin(11520);
  Serial.setTimeout(20);
}

void loop() {
  if (Serial.available() && Serial.read() == 'z') {
    int port = Serial.parseInt(SKIP_WHITESPACE);
    float power = Serial.parseFloat(SKIP_WHITESPACE);
    setPower(port, power);
  }
}

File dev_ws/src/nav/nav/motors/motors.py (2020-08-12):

import RPi.GPIO as GPIO
import time

import rclpy
from rclpy.node import Node
from rclpy.qos import qos_profile_sensor_data, QoSProfile

from std_msgs.msg import String
from geometry_msgs.msg import Twist

from nav.motors.SerialMotor import SerialMotor
from nav.motors.motor_constants import *


class Motors(Node):

    def __init__(self):
        super().__init__('motors')

        p = qos_profile_sensor_data
        p.depth = 1

        self.subscription = self.create_subscription(
            Twist,
            'cmd_vel',
            self.listener_callback,
            p)
        self.subscription  # prevent unused variable warning

        self.sm = SerialMotor("/dev/ttyACM1")
        self.get_logger().info('Motors Node Live')

    def convert_velocity_to_power(self, vel):
        """
        pseudo regression to convert wheel velocities
        to power commands
        """
        if vel == 0:
            return 0

        neg = False
        if vel < 0:
            vel = -1 * vel
            neg = True

        power = 1.3375 * vel - 0.5473

        if power > .8:
            power = .8
            self.get_logger().info('Exceeded maximum wheel power')
        if power <= .4:
            self.get_logger().info('Low wheel power')
            power = .4
        if neg:
            power = -1 * power

        return power

    def listener_callback(self, twist):
        self.get_logger().info('Twist  Linear: %.6f Angular: %.6f' %
                               (twist.linear.x, twist.angular.z))
        WHEEL_BASE = .15  # distance between wheels, meters
        RADIUS = .035  # wheel radius, meters
        right_vel = (twist.linear.x - twist.angular.z * WHEEL_BASE / 2.0) / RADIUS
        left_vel = (twist.linear.x + twist.angular.z * WHEEL_BASE / 2.0) / RADIUS
        self.get_logger().info('Velocity  Right: %.6f Left: %.6f' %
                               (right_vel, left_vel))
        right_power = self.convert_velocity_to_power(right_vel)
        left_power = self.convert_velocity_to_power(left_vel)
        self.get_logger().info('Power Right: %.3f Left: %.3f' %
                               (right_power, left_power))

        self.sm.set_motor(3, right_power)
        self.sm.set_motor(4, left_power)


def main(args=None):
    rclpy.init(args=args)

    motors = Motors()

    rclpy.spin(motors)

    # Destroy the node explicitly
    # (optional - otherwise it will be done automatically
    # when the garbage collector destroys the node object)
    motors.destroy_node()
    rclpy.shutdown()


if __name__ == '__main__':
    main()

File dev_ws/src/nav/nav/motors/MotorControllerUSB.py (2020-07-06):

import RPi.GPIO as GPIO
import time
from nav.motors.SerialMotor import SerialMotor
from nav.motors.motor_constants import *

sm = SerialMotor("/dev/ttyACM1")


class MotorControllerUSB:

    def setSpeed(self, speed):
        # speed is a percentage ---> 50 is 50% speed, 100 is 100% speed
        self.speed = speed/100

    def turn(self, degrees):
        consistentError = OFFSET
        turnConstant = TURN + consistentError*(1-self.speed)
        degreesToTime = turnConstant * (abs(degrees)/90) / (self.speed)       
        if (degrees < 0):
            time.sleep(degreesToTime)
            sm.set_motor(3, -self.speed)
            sm.set_motor(4, self.speed)
            time.sleep(degreesToTime)
        else:
            time.sleep(degreesToTime)
            sm.set_motor(3, self.speed)
            sm.set_motor(4, -self.speed)
            time.sleep(degreesToTime)
        sm.set_motor(3, 0)
        sm.set_motor(4, 0)

    def move(self, meters):
        moveConstant = MOVE
        metersToTime = abs(meters)*moveConstant/self.speed
        time.sleep(metersToTime)
        if(meters < 0):
            sm.set_motor(3, -self.speed)
            sm.set_motor(4, -self.speed)
        else:
            sm.set_motor(3, self.speed)
            sm.set_motor(4, self.speed)
        time.sleep(metersToTime)
        sm.set_motor(3, 0)
        sm.set_motor(4, 0)

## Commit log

2020-05-28 modified motor constants operation
2020-05-28 cleanup camera code and constants
2020-05-28 arduino motor code for USB
2020-05-28 experimental camera code
2020-05-28 motor code cleanup
2020-06-04 additional motor scripts
2020-06-04 containing folder needed for arduino motor file
2020-06-04 functional rolling and imu readings
2020-06-19 imu functional
2020-06-26 new action and motor architecture
2020-07-01 position pid action progress
2020-07-01 client for position pid
2020-07-02 bug fixes for pid messaging
    [motors.py]
2020-07-02 improved imu api and library
2020-07-02 modified motor packages and increased baudrate
2020-07-02 motor conversion organizational changes
2020-07-02 added conversion ratio for velocity to motor power
2020-07-06 reorganized motor files
2020-07-06 pid converted to multithreaded execution
2020-07-10 turtle pid and new trig
2020-07-10 functional turtle pid and construction progress on rover pid
2020-07-15 new parameter based tuning and turtle implementation for PID
2020-07-17 trig fixes complete for turtle position pid
2020-07-19 PlotJuggler functional
    [fake_joints.csv, simple.csv]
2020-07-24 sensor data qos
2020-08-01 change motor interface commands
2020-08-03 motor interface change
2020-08-03 update motor interface to match SerialMotor
2020-08-04 switched turning signature signage
2020-08-09 motor test script
2020-08-10 3D parts additions
    [9V_clip_mount.stl, DWM_BNO055_mount.stl, batt_regulator_mount.stl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]
2020-08-12 camera code cleanup
2020-08-13 new turn pid
2020-08-13 pid alterations
2020-08-13 motor basics additions
